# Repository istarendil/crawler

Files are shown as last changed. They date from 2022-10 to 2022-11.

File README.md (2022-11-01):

# Crawler robot
The **crawler robot** is a simple and low-cost physical platform for the initial study of [reinforcement learning](https://en.wikipedia.org/wiki/Reinforcement_learning) algorithms. It consists of a 2 DoF planar arm actuated by servomotors mounted on a mobile base with 2 free wheels .<br>

crawler
 <br>
The reinforcement learning algorithm used for the robot to find a sequence of actions that provide locomotion by its own is known as [**Q-learning**](https://es.wikipedia.org/wiki/Q-learning). The agent starts by executing random movements with his arm and when some sequence manages to mobilize the platform, the robot receives a positive reward. It is the repetition of this reward process that allows the robot to strengthen the movements that give it consistent locomotion and ignore the ones that do not.

policy

# Tools and materials
- Ardunio Uno board
- Matlab 2018
- 2 hobby servomotors
- Optical enconder 
- Bluetooth module
 
 # Demo
- The robotic agent [performing random movements](https://www.youtube.com/watch?v=am49DNG4l4M&list=PLQBwkbxMqU0CwwgrcaWHP4ouFjho0Iy4H&index=5) in order to learn an **optimal policy** through negative feedback.
- The robotic agent [executing a locomotion strategy](https://www.youtube.com/watch?v=am49DNG4l4M&list=PLQBwkbxMqU0CwwgrcaWHP4ouFjho0Iy4H&index=5) through a set of self-learned coherent movements

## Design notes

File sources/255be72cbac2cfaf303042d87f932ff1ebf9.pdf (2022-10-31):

## Teaching Reinforcement Learning using a Physical Robot

Michel Tokic | michel.tokic@hs-weingarten.de
Institute of Applied Research, University of Applied Sciences Ravensburg-Weingarten, Germany
Haitham Bou Ammar | haitham.bouammar71@googlemail.com
Department of Knowledge Engineering, Maastricht University, The Netherlands

Abstract

This paper presents a little crawling robot as a didactic instrument for teaching reinforcement learning. The robot learns a forward-walking policy from scratch in less than 20 seconds of reinforced sensorimotor interactions. The state space consists of two discretized dimensions, where the behavior is visualizable and comprehensible. In laboratory tutorials, students conduct experiments with a Toolbox written in Java, enabling to vary significant parameters such as the exploration rate or the discounting factor. Our experience as well students feedback in using the crawler reflects: (1) a more interesting lecture, (2) an increase in students’ motivation, and (3) an efficient and fast learning for students.

### 1. Introduction

Machine Learning is a fast growing field. Applications such as recommender and/or ranking systems are embedded in most search engines and social networking sites. Various other applications such as the Google driverless car and robotics, among others, are paving the way for new technologies and products in the near future.

Such applications raise a broad interest in learning about this new and exciting technology. For instance, over 100, 000 students attending Andrew Ng’s online lecture on Machine Learning clearly reflect this increasing interest. This interest elevation comes at the expense of providing the best tools to convey such a knowledge in an efficient and suitable manner. Machine learning is a massive field, which includes dif-

Appearing in Proceedings of the Workshop on Teaching Machine Learning at 29 th International Conference on Machine Learning, Edinburgh, Scotland, UK, 2012.

ferent areas of study. In an introductory course, typically few hours are assigned to reinforcement learning (RL), a technique for acquiring behavior based on reinforced sensorimotor interactions (Sutton and Barto, 1998). Aiming at conveying such a knowledge efficiently, we are looking for a vivid presentation of these various techniques. In particular we are looking for a simple to understand physical robot as a motivator for AI students (Kay, 2010). For starters and to better understand the delivered material, it is important to be able to visualize various aspects of the used algorithms, therefore, the learning problem should consist of a two dimensional state space. A robot fulfilling these requirements is the crawler (Kimura et al., 1997; Tokic et al., 2009) with its two degrees of freedom arm, shown in Figure 1. To couple the physical robot with a software kit, that allows the students to easily program a learning behavior, the open-source Teaching-Box has been introduced in former research (Ertel et al., 2009). This kit is implemented in Java and contains abstracted basic RL algorithms, allowing to design arbitrary experiments with this technology.

In this paper we reflect upon experience in using the crawler as an example of a physical demonstration in introductory AI courses (Ertel, 2011). It was clear that such a scheme has: (1) increased a students’ interest and motivation to learn about reinforcement learning, and (2) made the lecture more exciting as there is a hands-on and easy to experiment-with example.

### 2. The Crawler and Teaching-Box

The physical robot, shown in Figure 1, is a two degrees of freedom arm. The state space is described using the discrete joint angles gx and gy shown in Figure 2. The goal of the robot is to move forward. Therefore, the reward is the speed of the robot, i.e. the distance the center of gravity of the robot had moved in a given time step. Consequently, a positive reward is attained if the robot moves forward and a

Teaching Reinforcement Learning using a Physical Robot

negative one vice versa. The robot is controlled by an ATmega32 micro-controller board mounted at its top as shown in Figure 1(b). The joints of the robot are driven by servos and the robot’s movement–used to calculate the velocity–is measured using an optical encoder attached to one of the wheels. The board has outlets for the servos, a serial wireless transceiver, an outlet for the encoder, and a DIP switch to set various parameters.

(a) (b)
robot | time | state | reward | action
| | 0 | up | left | 0 | right
| | 1 | up | right | 0 | down
| | 2 | down | right | 0 | left
| | 3 | down | left | 1 | up
t | gy | gx | x | at

(c)

Figure 1. (a) The robot model with its two joints and the
(b) physical robot. Four steps of a simple forward-walking policy are shown in (c).

### 2.1. Reinforcement Learning

Reinforcement Learning (RL) is a technique for solving sequential decision making problems (Sutton and Barto, 1998). Typically, a learning problem is described as a Markov Decision Process (MDP) that basically consists of a state space, S, an action space, A, transition probabilities, P(s, a) : S × A × S → [0, 1] with s ∈ S and a ∈ A, a reward function R : S × A × S → R, and a discount factor γ ∈ [0, 1[. The goal in RL is to learn a policy π : S × A → [0, 1], with π(a|s) defining the probability of choosing action a in state s. The goal of an RL agent is to learn π so as to maximize the total discounted reward, defined by an utility function, V

π
(s) = Eπ

P∞
k=0 γ

k
rt+k+1|st = s

Algorithm 1 ValueIteration On The Crawler
1: Initialize V arbitrarily, e.g., V (s) = 0, for all s ∈ S

2: Initialize Ra
ss⁰ arbitrarily, e.g., r(s, a) = 0, for all r ∈ Ra
ss⁰
3: state ← (gx = 1, gy = 1)

4: loop
5: | ξ ← rand(0..1)
6: | if ξ < ε then
7: | a ← rand(A(state))
8: | else
9: | a ← argmaxaRa ss⁰ + γV (s
| 0
)
10: | end if
11: | successorState ← δ(state, a)
12: | observe r(state, a) and update Ra ss⁰
13: | for all s ∈ S do
14: | V (s) ← max a∈A(s)

h
| r(s, a) + γV δ(s, a)

i

15: | end for
16: | state ← successorState
17: end loop
gx | 1 | 2 | 3 | 4 | 5
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
↑↓ ↑↓ ↑↓ ↑↓ ↑↓
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
↑↓ ↑↓ ↑↓ ↑↓ ↑↓
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
↑↓ ↑↓ ↑↓ ↑↓ ↑↓
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
↑↓ ↑↓ ↑↓ ↑↓ ↑↓
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
↓ | ↓ | ↓ | ↓ | ↓
↓ | ↓ | ↓ | ↓ | ↓

J

↓ | ↓ | ↓ | ↓ | ↓
→

J→

J→

J→

J

J

↑ | | | | ↓
←

J←

J←

J←

J

Figure 2. The cartesian 5 × 5 grid-world model (left) and a cyclic walking policy (right). States within the cycle are labeled as J.

### 2.2. Reinforcement Learning on the Crawler

There are different suggested algorithms for solving the crawler problem. In assignments and lab tutorials for the introduction to AI course, we use a simplified Value Iteration algorithm without using transition probabilities. This scheme is described in Algorithm 1, which starts by initializing all state values to arbitrary numbers such as zeros. Starting from the upper left corner, stateinit = {gx = 1, gy = 1}, an action can be chosen according to an ε-greedy exploration policy. An action a performed in state transitions the arm to a neighboring successor state, state⁰ ← δ(state, a). The distance the robot moved forward/backward is utilized as the reward signal rt+1, which is measured as encoder tics after sending the action command to the servos. Subsequently the reward is memorized in the reward model Ra
s,s⁰ . Next, for all states the value iteration algorithm is performed using the so far sampled reward model Ra

s,s⁰ . Finally, the observed successor state, state⁰
, is
taken as the new actual state of the robot.

Students experimentation in this specific example is conducted by programming the previous algorithm within the Teaching-Box, explained in Section 2.3. The parameters γ and , as well as others, are allowed to vary so as to assess the behavior of the algorithm. This enables for a better understanding of RL and the overall problem.

### 2.3. Teaching-Box

In order to easily program RL algorithms for the crawler, we provide a simple Java software kit that allows: (1) test the efficacy of the algorithm in simulation, and (2) apply the algorithm on the real physical robot to see it running. The Teaching-Box (TB) is an easy to use Java RL library, which includes basic RL algorithms, e.g., Q-learning(λ) and SARSA(λ), as well function approximators such as CMACs or radial basis function networks. The TB is implemented in a way to easily allow students to directly vary parameters of the algorithms, generate plots, and other visualizations to better assess the quality of the learned behavior.

### 3. Class Room Experience

The crawler is used in AI classes for computer science master students in the second semester. For the laboratory tutorial lasting about 1.5 hours, basic knowledge of the Java programming language is required. At first, it is demonstrated how the crawler learns to walk forward in about 20 seconds. Further, the technicality and difficulty of the learning problem are explained as in Figure 1+2, by basically reflecting on the delayed feedback problem. This alone is able to raise interest for understanding the details of the problem. Then, the basic algorithms for solving MDPs are introduced, e.g., value iteration and Q-learning, which afterwards enables to start conducting experiments on the robot.

A typical task for a student is to observe and assess the robot’s learning behavior on different surfaces, for instance by comparing the progress of the robot through examining the learned V and reward functions, or measuring the traveled distance in a fixed time interval. Another experiment is the variation of the algorithmic parameters such as the discount factor or the exploration rate. For instance, if the exploration rate is set to one, then the robot will perform 100% random actions. In contrast, if the exploration rate is constantly set to zero, the robot will be completely exploit the current V -values, which rarely leads to the optimal policy in practice, and to sub-optimal cycles instead, see Figure 3. This allows to better understand the dilemma of exploration and exploitation inherent to reinforcement learning. In other experiments, using for example the Q-learning algorithm, students observe a much slower learning behavior. This is because standard Q-learning updates only one Q-value after performing an action, but which might be improved by utilizing eligibility traces (Singh and Sutton, 1996) in simulation. However, on the hardware robot using the ATmega32 microcontroller, we only have 2kB of memory, for which reason we found the modified value iteration algorithm to perform best.

Due to the small state space and the idea of being able to visualize basically everything in the algorithm, students are usually highly motivated in starting to program the physical robot. Furthermore, a lot of interesting questions and discussions are initiated, for instance, extensions to continuous states and/or actions spaces are of major interest. Other questions on how to best choose the algorithmic parameters were also detailed and further analyzed. Starting from this simple example, some students even decided to further pursue bachelor and master theses in our groups.

### 4. Conclusions

In this paper we have presented an idea of using the simple crawling robot in teaching introductory machine learning courses. The robot is described by a 5 × 5 grid world, for which reason it is easy to understand and visualize. The hands-on physical experiment using the TB has raised the interest and motivation by students to better understand and analyze the subject, which allows to asses the behaviors of certain parameters involved in the algorithmic design process. Our experience with such type of learning is positive and we like to recommend using such a system at different universities all over the world. The software kit is open-source and available for anybody to use¹ .
Demonstration videos and contact addresses for obtaining the robot are also available²
. In the current
SVN trunk, a beta release of a three dimensional visualization of the robot using PythonGL is also provided, which does not require to own the hardware robot. Besides this, the group of Jennifer S. Kay at

1
http://sourceforge.net/projects/teachingbox
2
http://www.tokic.com

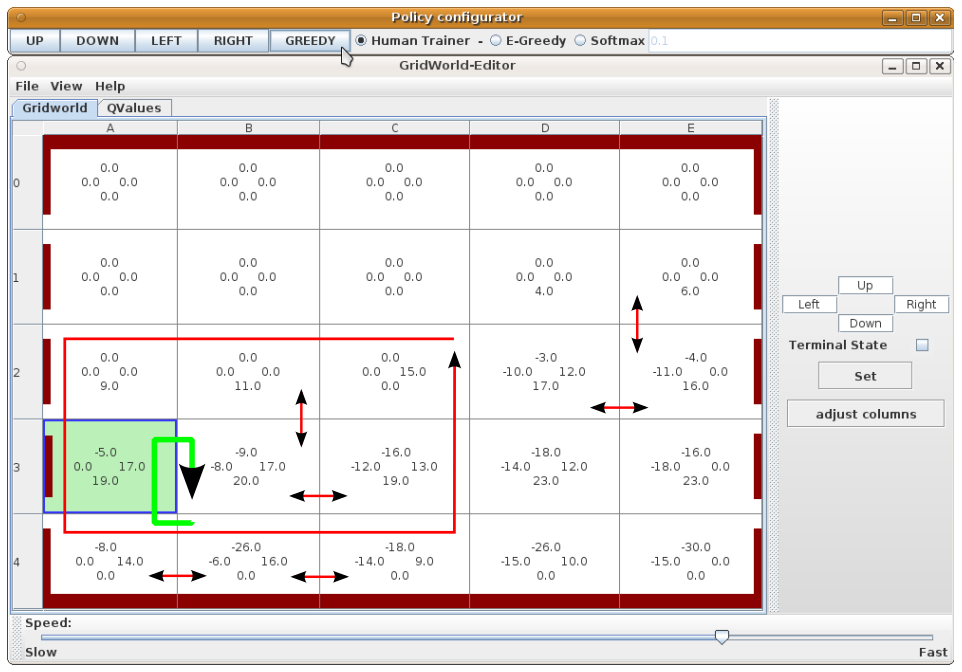
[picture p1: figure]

Figure 3. The grid-world editor of the Teaching-Box showing on top the ability to configure an action-selection policy. Numbers in cells indicate the reward r(s, a) observed from the environment. The cycle A3→B3→B4→A4 indicates the optimal cycle having an average reward of ¯r =

17+20−6−8
4 = 5.75 per action. All other marked cycles are sub-optimal, i.e. having a lower average reward/action ratio compared to the optimal cycle. The cell with surrounded border (A3) indicates the current state of the robot.

Rowan University currently develops a version of the
crawler utilizing LEGO Mindstorms (Montresor et al., 2011). Once finished, we plan to integrate it into the TB as well.

Acknowledgements

We like to thank Wolfgang Ertel and Jennifer S. Kay for sharing their experiences using the crawler.

References

W. Ertel. Introduction to Artificial Intelligence. Springer, 2011.
W. Ertel, M. Schneider, R. Cubek, and M. Tokic. The Teaching-Box: a universal robot learning framework. In International Conference on Advanced Robotics ICAR’09, pages 1–6, 2009.
J. S. Kay. Robots as recruitment tools in computer science: The new frontier or simply bait and switch? In AAAI Spring Symposium: Educational Robotics and Beyond, Technical Report SS-10-03. AAAI, 2010.
H. Kimura, K. Miyazaki, and S. Kobayashi. Reinforcement learning in POMDPs with function approximation. In Proceedings of the 14th International Conference on Machine Learning (ICML’97), pages 152–160, San Francisco, CA, USA, 1997. Morgan Kaufmann Publishers Inc.
S. Montresor, J. Kay, M. Tokic, and J. Summerton. Work in progress: Programming in a confined space - a case study in porting modern robot software to an antique platform. In Proceedings of the 41st ASEE/IEEE Frontiers in Education Conference, pages T3H–1–T3H–3, Rapid City, SD, USA, 2011. IEEE Press.
S. Singh and R. S. Sutton. Reinforcement learning with replacing eligibility traces. Machine Learning, 22:123–158, 1996.
R. S. Sutton and A. G. Barto. Reinforcement Learning: An Introduction. MIT Press, Cambridge, MA, 1998.
M. Tokic, J. Fessler, and W. Ertel. The crawler, a class room demonstrator for reinforcement learning. In Proceedings of the 22th International Florida Artificial Intelligence Research Society Conference, pages 160–165, Menlo Park, USA, 2009. AAAI Press.

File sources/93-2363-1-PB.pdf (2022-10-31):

## The Crawler, A Class Room Demonstrator for Reinforcement Learning

Michel Tokic and Wolfgang Ertel and Joachim Fessler
ZAFH Servicerobotik
University of Applied Sciences Ravensburg-Weingarten Doggenriedstrasse 38
88241 Weingarten, Germany

Abstract

We present a little crawling robot with a two DOF arm that learns to move forward within about 15 seconds in real time. Due to its small size and weight the robot is ideally suited for classroom demonstrations as well as for talks to the public. Students who want to practice their knowledge about reinforcement learning and value iteration can use a wireless connection to a PC and monitor the internal state of the robot such as the value function or the reward table. Due to its adaptivity, depending on the surface properties of the underground the robot may surprise its audience with unexpected but efficient walking policies. The GUI is open source and the robot hardware is available as a kit from the authors.

Introduction
In a classical introductory AI class, reinforcement learning has a narrow time slot of a few hours only. In our AI class we introduce value iteration (Bertsekas 1987) and Q-Learning (Watkins 1989) on discrete state- and action spaces and explain the exploration problem. Finally we give a short outlook on continuous problems and other algorithms.
In order to give a vivid presentation, we were looking for an example of a simple robot that enables us to directly demonstrate the learning algorithms. The state space of such a robot has to be two dimensional and the actions of the robot should be moves to neighbor states in the two dimensional grid world. A robot that very nicely fulfills these requirements was presented as a simulation in (Kimura, Miyazaki, and Kobayashi 1997). Figure 1 shows an outline of the little crawling robot with a two degree of freedom arm. In case of discrete positions and small movement angles of the two joints the state space can be approximated by a cartesian grid world as shown in Figure 2.
To move forward, the robot has to repeatedly perform a cycle of moves. An example for such a cycle is shown in Figure 2 on the right or in the sequence shown in Table 1. The task for the learning algorithms is to find a policy (which might be such a cycle) that maximizes the long-term cumulative reward. The reward is the speed of the robot, i.e. the distance the body of the robot moves forward per time step. Consequently, a move forward gives positive reward whereas any backward move yields negative reward.

Copyright -c 2009, Association for the Advancement of Artificial Intelligence (www.aaai.org). All rights reserved.

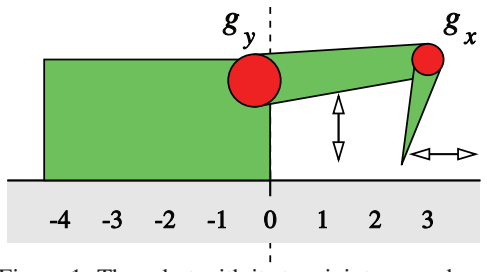
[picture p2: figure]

Figure 1: The robot with its two joints gx and gy.

gx 1 | 2 | 3 | 4 | 5

gy
1 -

←→-

←→-

←→-

←→-↑↓ ↑↓ ↑↓ ↑↓ ↑↓
2 -

←→-

←→-

←→-

←→-↑↓ ↑↓ ↑↓ ↑↓ ↑↓
3 -

←→-

←→-

←→-

←→-↑↓ ↑↓ ↑↓ ↑↓ ↑↓
4 -

←→-

←→-

←→-

←→-↑↓ ↑↓ ↑↓ ↑↓ ↑↓
5 -

←→-

←→-

←→-

←→-

↓↓↓↓↓

↓↓↓↓↓

↓↓↓↓↓
→-

→-

→-

→-

↑ | ↓
←-

←-

←-

| ←-

Figure 2: The cartesian 5 × 5 grid-world model (left) and a cyclic walking policy (right). States within the cycle are labled as -.

As a last but important requirement, the robot has to be small, lightweight and autonomous, such that it can easily be taken to the class room in a brief case and be demonstrated without an external power supply.
In the following sections we describe the robot hardware, the robot software and a graphical user interface (GUI) on the PC with a wireless connection to the real robot (Tokic 2006). For didactic purposes the GUI is very helpful because it allows us to view the value table and reward table and to watch the learning process of the robot.

The Robot
Hardware Setup
Our crawling-robot prototype as depicted in Figure 3 is controlled by an ATmega32 microcontroller board which

# 160 Proceedings of the Twenty-Second International FLAIRS Conference (2009)

robot | time | state | | reward | action
| | 0 | up | left | 0 | right
| | 1 | up | right | 0 | down
| | 2 | down | right | 0 | left
| | 3 | down | left | 1 | up
t | gy | gx | x | at

Table 1: Four steps of a simple cyclic forward walking policy.

is mounted on top of the robot. The joints of the robot are driven by servos and the robot’s movement is measured by an optical incremental encoder attached to one of the wheels. The board has outlets for the servos, a serial wireless transceiver, an outlet for the encoder and a DIP switch to setup several parameters. For instance one of these parameters inverts the encoder signal such that the robot learns a backward-moving strategy instead of moving forward.

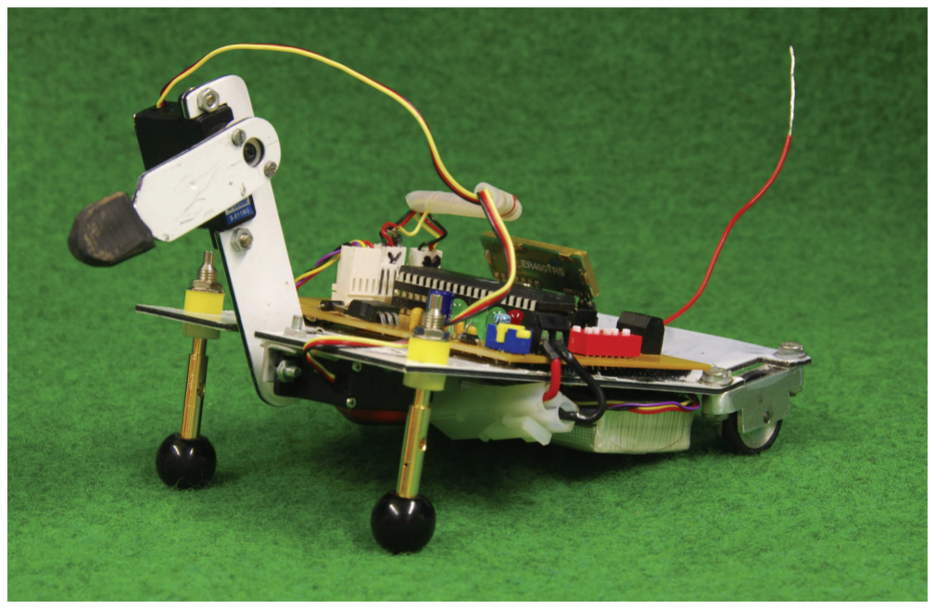
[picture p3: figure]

Figure 3: The crawling-robot prototype.

In addition to this prototype we developed a new version of the crawling robot as shown in Figure 4. Due to its robustness this robot is more suitable for lectures and laboratory tutorials. It has two wheels at the rear with a rigid axle. The axle is connected via a non-slip belt transmission to the encoder. This assembly reduces the sensor noise to a minimum. The board has the same features as the board above but with a bus interface for Dynamixel AX-12 servos in addition. These servos communicate with a half-duplex asynchronous packet-protocol on TTL-level with up to 1,000,000 bps. The maximum holding torque is about 1.17 Nm.

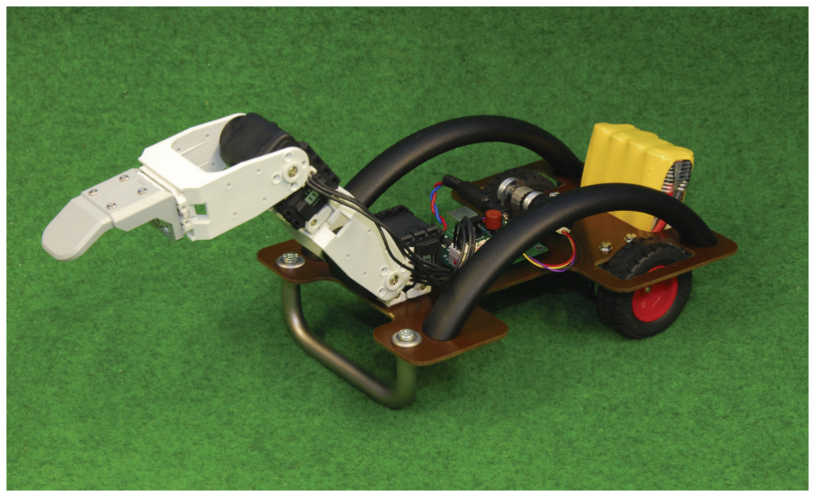
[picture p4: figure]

Figure 4: The new crawling robot for use in our laboratory tutorials.

The Learning Algorithm
We consider the reinforcement learning framework, see for example (Sutton and Barto 1998), where an agent, in our case the crawling robot, interacts with a Markovian decision process (MDP). At each time t ∈{0, 1, 2, ...} the agent is in a certain state st ∈S. After executing action at ∈A the agent receives a reward signal Ra
ss-

= E{rt+1|st =
s, at = a, st+1 = s-
} by passing into a successor state st+1 with probability Pa
ss-

= Pr{st+1 = s-|st = s, at = a},
∀s, s-
∈S,a ∈A. δ(s, a) denotes a transition function and represents the successor state safter action a has been
selected in s. The decision which action a is chosen in a certain state s is characterized by a policy, π(s)= a, which could also be stochastic π(s, a)= Pr{at = a|st = s}. A policy which maximizes the average reward over time is denoted as π∗. On the crawling robot we use the valueiteration algorithm (Bertsekas 1987; Sutton and Barto 1998; Powell 2007) for learning a cyclic deterministic policy π(s) by which the robot moves forward. The algorithm value iteration which we use on the robot basically works by assigning a numerical value V (s) ∈V to each state s ∈S where each state value represents the expected cumulated reward over time when following π(s). Based on these state values V in conjunction with Ra
ss-

a deterministic policy π(s) can be derived.
We adapted the value-iteration algorithm to perform on the crawling robot as depicted in Algorithm 1. Here a discounting factor 0 <γ ≤ 1 is used to specify the portion of influence of neighbor-state values V (δ(s, a)) on V (s). Since the robot is faced with a zero-knowledge environment after switching it on, a tradeoff between exploration (long-term optimization) and exploitation (short-term optimization) has to be done (Thrun 1992; Kaelbling, Littman, and Moore 1996; Sutton and Barto 1998). A very simple exploration technique is ε-Greedy exploration. Here the agent selects an action at random with a probability ε, uniformly and independently of V (s), instead of following π(s). Heuristically ε could be set to a high value at the beginning of the learning process and then be decreased over time. This ensures much exploration at the beginning and pure exploitation starting at some time t.

Algorithm 1 VALUEITERATION ON ROBOT
1: Initialize V arbitrarily, e.g., V (s)=0, for all s ∈S 2: Initialize Ra
ss-

arbitrarily, e.g., r(s, a)=0, for all r ∈
Ra
ss-3: state ← (gx =1,gy = 1)

4: loop
5: | ξ ← rand(0..1)
6: | if ξ<ε then
7: | a ← rand(A(state))
8: | else
9: | a ← argmaxaRa ss- + γV (s- )
10: | end if
11: | successorState ← δ(state, a)
12: | observe r(state, a) and update Ra ss-
13: | for all s ∈S do
14: | V (s) ← maxa∈A(s) r(s, a)+ γV (δ(s, a))
15: | π(s) ← argmaxa∈A(s)r(s, a)+ γV (δ(s, a))
16: | end for
17: | state ← successorState
18: end loop

As the value-iteration algorithm requires the rewards r(s, a) for each action a in state s, we simply save them into a memory table Ra
ss-

. After executing action a in s, we update the corresponding record r(s, a) in Ra
ss-

The Robot Software
The robot’s software architecture runs autonomously in a single thread on the ATmega32 microcontroller. This microcontroller comes with four “pulse-width modulated” (PWM) pins. We use two PWM-pins associated with Timer1A/B to directly position the joint-servos. The optical incremental encoder which is connected to an external-interrupt pin provides the reward signal r(s, a). An interrupt-service routine (ISR) counts the distance the robot moved within a small delay time t. It is activated subsequently after setting up the Timer1A/B registers by which we position the servos with respect to state s and action a.
In an endless loop the robot executes actions either with respect to the learned policy π(s) or exploration steps. After each action a value-iteration step for all s ∈S is performed. Subsequently the serial interface is polled to check if the GUI sent a command to which the microcontroller should respond. For instance such a command can be a request for transmitting V and Ra
ss-

to the GUI in order to display the robot’s “brain”.

Walking Robot Simulation
To demonstrate and test reinforcement learning algorithms on the two-dimensional grid-world, we developed a graphical user interface (GUI) which allows control of the real hardware robot and a simulated version of it. In addition to an animation of the robot’s x-z-projection the GUI comes up with a reward editor, a display of the current value table and a view of the current policy, Figures 5 and 6. A configuration editor enables the user to select the size of the state space and to specify the learning algorithm parameters, for example the discounting factor γ. In the configuration dialog it is also possible to configure a neural network for approximating the V -Function using back- or resilientpropagation (Rumelhart, Hinton, and Williams 1986; Riedmiller and Braun 1992).
In the view of the value table the user is able to control value iteration step-by-step using the “next iteration”-button. As well it is also possible to run the learning algorithm in a time-delayed or full-CPU-speed loop. Due to this feature the user can observe the robot’s learning progress over some time period. For this in each robot state s, which is a cell in the value table, we also display an arrow respresenting the robot’s current policy π(s) as shown in Figure 5.

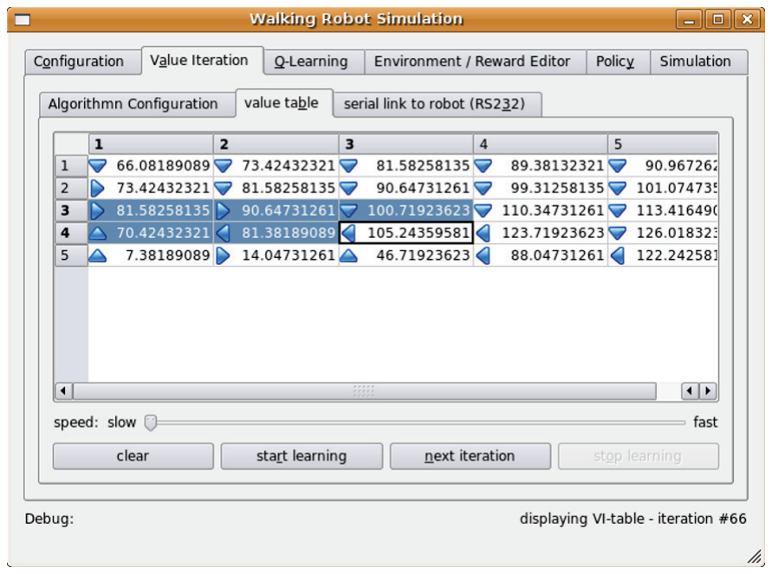
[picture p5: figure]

Figure 5: The simulator’s value table view with arrows for the current policy in each state. Please note the marked cyclic policy which the hardware robot learned after executing 66 value-iteration steps with respect to the environment as displayed in Figure 6.

Another important feature of the simulator is the reward editor as depicted in Figure 6. It allows the user to model the agent’s environment and thus to simulate the real hardware robot on different grounds. Alternatively the hardware robot’s reward table Ra
ss-

is displayed in this view when the simulator is connected to the robot. In combination with the robot’s value table this enables the user to get an insight into the robot’s “brain”. In the next section we will show how the simulator can be used by students to model different robot environments.
Apart from simulating the crawler, the simulator can also be used to simulate arbitrary two dimensional grid worlds with the four actions left, right, up and down.

Serial Robot Interface
One of the GUI’s main features is the serial robot interface by which the user is able to communicate wireless with the hardware robot. The interface enables the user to analyze the

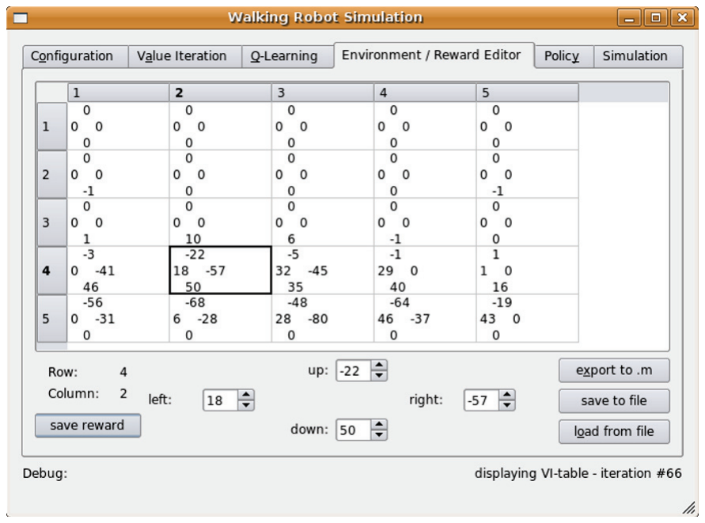
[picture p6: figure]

Figure 6: The simulator’s reward editor displaying the hardware robot’s reward table Ra
ss-

robot’s learning progress and to setup several learning process specific parameters. The link is realized by a RF04/400 USB telemetry module on the PC side, connected to the USB port. On the microcontroller side, we use an Easy-Radio ER400TRS transceiver which is directly connected to the microcontroller’s USART pins and which is also a part of the RF04/400 USB telemetry module. The two transceivers operate at the 433MHz frequency band with a serial baudrate of 19200. The GUI view provides to the user the following features:

- send control commands to the robot, e.g. “start walking” or “stop walking”
- retrieval of Ra
ss-

and V from the robot
- transfer Ra
ss-

and V from the GUI to the robot
- configuration of the robot’s discounting factor γ
- configuration of the robot’s exploration parameter ε
- retrieval of a counter, c, that indicates what distance the robot moved forward since the last counter reset
- reset of the distance counter c

Class Room Experience
We used the crawler in the AI class for the computer science master students. At the very beginning of the section on reinforcement learning we give a demonstration of the crawler learning to walk within about 20 seconds. This simple demo leads to a high motivation: the students want to know “how it works”. Then, after introducing value iteration, the students can perform their own experiments on the robot. Some of the possible experiments are described in the following.
In our laboratory tutorials a typical task for a student is to observe the robot’s learning behaviour on different surfaces. A part of this exercise is the examination of the robot’s learning progress by loading V and Ra
ss-

from the
robot into the GUI. This enables the student to identify the policy cycle and to verify it. This is done by computing

↓ ↓ ↓↓↓
→-

→-

↑ ↓↓↓
←-
| ←- ←- ←-
↑ ↑ ↑↑↑

↑↑ | ↑

→-

→-

→-

↓↓↓↓

→-

↑↓↓↓↓

→-←-

←-↑↑

↓↓ ↑↑

→-

→-

→-

Figure 7: Left: The robot’s policy learned on the laboratory carpet as depicted in Figure 3. Right: The robot’s policy learned on a table with a slippery surface as depicted in Figure 8. States within the cycles are labeled as -.

the average reward which is the ratio of the cumulated reward and the number of actions within the cycle. In the example of Figures 5 and 6 the robot’s average reward is
0+0+6+32+18−3
6 | =8.833. Afterwards the students simulate
the behaviour with a different discounting factor γ to get a sense about the effect of γ on learning times. For example a low γ leads to short learning times because value iteration converges faster. But unfortunately this leads to the problem that the optimal cycle is eventually not learned and sub-optimal cycles are learned instead of the optimal one. Since V (s) respresents the expected reward in the future, this effect is caused by too little information about states farther away from s. However solving this problem with a high
γ -
1 leads to longer learning times because value iteration converges slower. For the hardware robot we recommend γ =0.9 as the discounting factor since in all our experiments we got short learning times with it and we were able to find the optimal cycle.
Another parameter which can also be explored by the students is the exploration-rate parameter 0 ≤ ε ≤ 1. The choice of ε also impacts the learning time. For example, ε =1 leads to 100% exploration and the robot performs random actions all the time. On the other hand if ε =0, then the robot exploits greedily the current policy without exploring if there are other actions that yield more reward in the future. This effect is observable by the students as the robot will mostly stick in sub-optimal walking policies if ε =0 is configured. During the experiments the students find out that ε =0.1 is a good choice for balancing exploration and exploitation on this little crawling robot.
Some results of our experiments are shown in Figure 7 where the robot learned different policies due to different surface properties. We stopped the robot after a while of learning and examined the policy. The videos showing this learning process can be found on our laboratory website (AI-Lab HRW 2008).
Another very valueable exercise for the students is the inverse of the above task. Here the student has to design patterns of immediate rewards that simulate different surfaces on which the crawler has to move. Then the student uses the simulator to train a policy with value iteration. Now he/she can check if the policy meets the requirements.

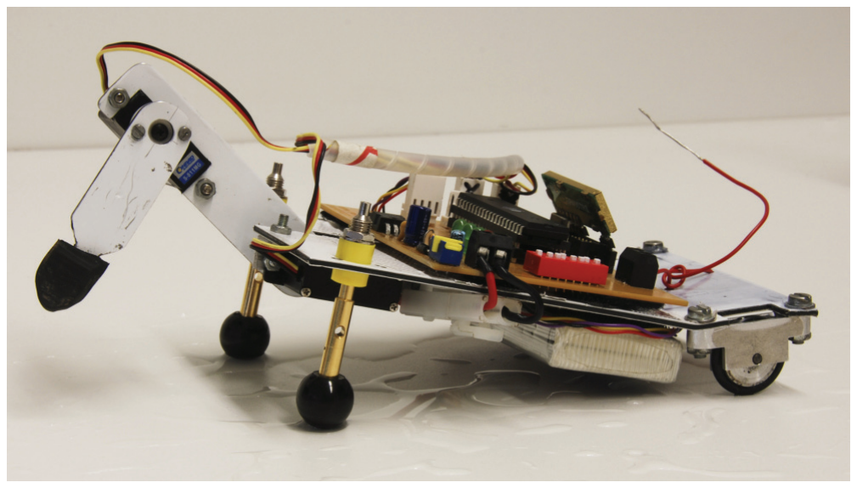
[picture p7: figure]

Figure 8: The crawling-robot prototype on a desk with a slippery surface.

As a first task, a flat surface is given. On such a ground, whenever the robot lifts its body a little bit, it can move effectively. An appropriate 5 × 5 reward pattern together with the resulting walking policy is given in Figure 9. With minimal vertical lifting, but maximal horizontal movement, the robot makes “big flat steps”.

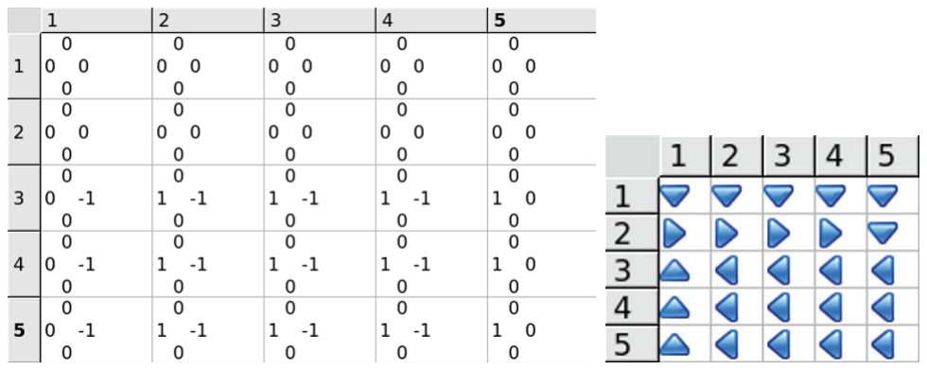
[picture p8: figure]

Figure 9: Simulated reward pattern for a flat surface (left) and the corresponding learned policy (right).

As a next task, the surface is rough, like it is if a human or animal walks in deep snow. Here the legs have to be lifted up high. Otherwise, the resistance or friction is very high. This can be modelled with high rewards if the body is lifted up high and low (but non-zero) rewards with small lifts. Figure 10 shows such a reward pattern together with the resulting walking policy.

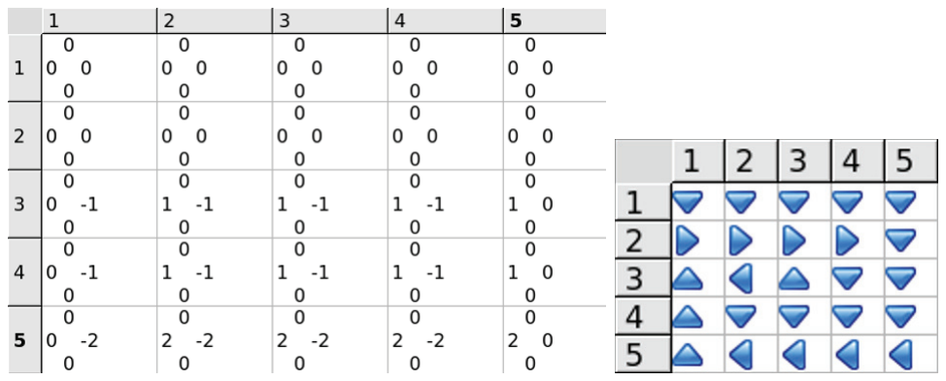
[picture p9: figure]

Figure 10: Simulated reward pattern for a rough surface (e.g. deep snow) and the corresponding learned policy.

Finally, the student can compare the simulated policies and reward patterns with the results from the experiments on the real robot. Differences are due to the fact, that for large angles of the robot joints, the geometry of the crawler movements is far from the Euclidean (rectangular) geometry in the simulation. This leads to the insight that even a robot as simple as our crawler can “invent” policies which a programmer never would have designed. For the students this is a very convincing motivation for the study of learning algorithms for robots.

Conclusions and Future Work

Due to the relatively small state- and action space the learning times on the real robot with its ATmega32 microcontroller are very short. Usually after about 10 to 30 seconds the value-iteration algorithm has learned a nice walking policy. Due to this impressive learning speed and its animal like shape and movements, in many lectures and talks the little crawling robot was able to attract the attention of students and spectators. Especially for an abstract and mathematically challenging subject such as reinforcement learning this is the best way of motivating students we can imagine. Even for us developers it was surprising to observe how sensible this very simple robot adapts its behaviour to the surface properties of the underground. The videos at (AI-Lab HRW 2008) show five policies learned on different surfaces. This can easily be demonstrated in the classroom e.g. by running the robot on a table or on a carpet and observing the difference.
Since this is an ongoing project we currently implement Q-Learning on the hardware robot as well as in the simulator as an alternative to value iteration. Once it is implemented the students are able to perform observations of the learning speed with respect to different learning algorithms. As a further extension we plan to implement different exploration/exploitation techniques, for example counter-based exploration as described in (Thrun 1992), since this will also impact the learning times.
Last but not least we want to encourage other universities to use this little robot for communicating the fascination in robot learning to their students. On our website (AI-Lab HRW 2008) we offer a hardware kit, an open-source simulator and the hardware robot’s open-source software.

Acknowledgements

We like to thank Hans-Peter Radtke, Markus Schneider, Arne Usadel and Tobias Bystricky for their contributions to the source code. We also thank Andy Stumpe and Christian Bieber for their support in taking measurements, video recordings and photos of the walking robot and for bringing the software to our website.
This work has been conducted within the ZAFH Servicerobotik (ZAFH 2008). The authors gratefully acknowledge the research grants of the state Baden-Wurttemberg and the ¨ European Union.

References

AI-Lab HRW. 2008. University of Applied Sciences
Ravensburg-Weingarten, Germany. | Website. | http:

//ailab.hs-weingarten.de [Online; accessed 20-February-2009].
Bertsekas, D. P. 1987. Dynamic Programming: Deterministic and Stochastic Models. Upper Saddle River, NJ, USA: Prentice-Hall, Inc.
Kaelbling, L. P.; Littman, M. L.; and Moore, A. P. 1996. Reinforcement Learning: A Survey. Journal of Artificial Intelligence Research 4:237–285.
Kimura, H.; Miyazaki, K.; and Kobayashi, S. 1997. Reinforcement Learning in POMDPs with Function Approximation. In ICML ’97: Proceedings of the Fourteenth International Conference on Machine Learning, 152–160. San Francisco, CA, USA: Morgan Kaufmann Publishers Inc. Powell, W. B. 2007. Approximate Dynamic Programming: Solving the Curses of Dimensionality. Wiley-Interscience. Riedmiller, M., and Braun, H. 1992. RPROP- A Fast Adaptive Learning Algorithm. Technical report, Proc. of ISCIS VII), Karlsruhe University, Germany.
Rumelhart, D. E.; Hinton, G. E.; and Williams, R. J. 1986. Learning Internal Representations by Error Propagation. Parallel Distributed Processing: Explorations in the Microstructure of Cognition, vol. 1: foundations 318–362. Sutton, R., and Barto, A. 1998. Reinforcement Learning: An Introduction. Cambridge, MA: MIT Press.
Thrun, S. B. 1992. Efficient Exploration In Reinforcement Learning. Technical report, Carnegie Mellon University, Pittsburgh, PA, USA.
Tokic, M. 2006. Entwicklung eines lernenden Laufroboters. Diploma thesis, University of Applied Sciences Ravensburg-Weingarten, Weingarten, Germany. Watkins, C. 1989. Learning from Delayed Rewards. Ph.D. Dissertation, University of Cambridge, England.
ZAFH. | 2008. | Zentrum fuer Angewandte Forschung
an Fachhochschulen. | Website. | http://www.
zafh-servicerobotik.de [Online; accessed 20-February-2009].

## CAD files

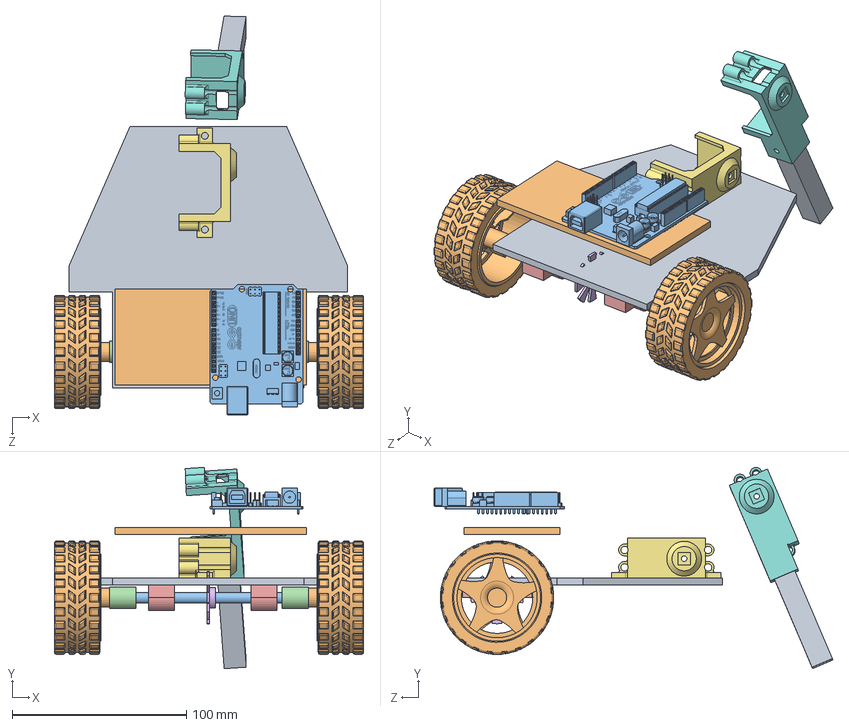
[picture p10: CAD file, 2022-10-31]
cad/Ensamblaje.SLDASM
177.4 x 115.6 x 228.9 mm
Chasis1
Rueda x 2
Eje
Cople x 2
Buje x 2
Encoder
Soporte2
Soporte
Brazo
Chasis2
Arduino UNO

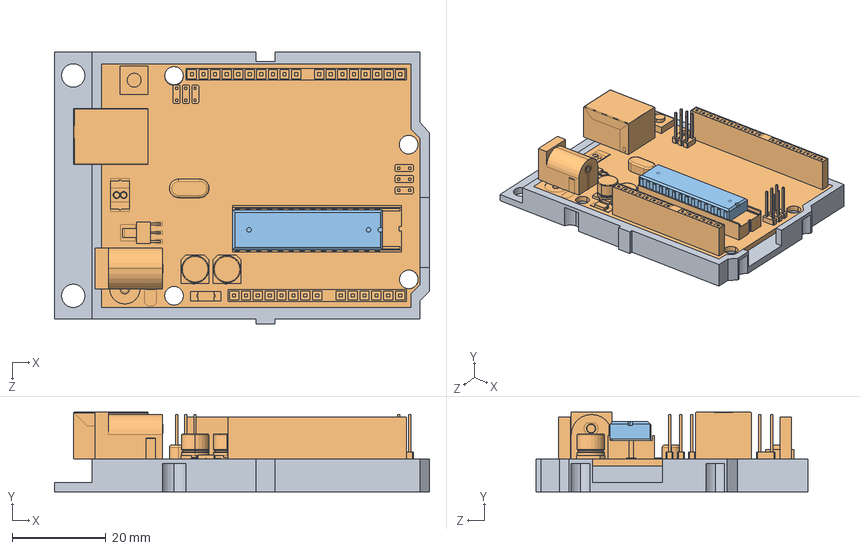
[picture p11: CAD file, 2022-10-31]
cad/Ardunio Uno .SLDASM
80.0 x 17.0 x 58.0 mm
Ardunio_holder.STEP
Ardunio-0.STEP
Top_chip.STEP

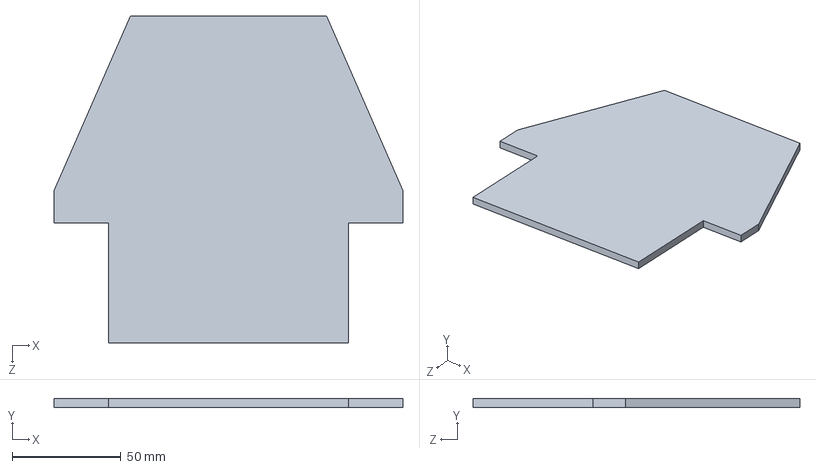
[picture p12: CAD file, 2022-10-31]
cad/Chasis1.SLDPRT
160.0 x 4.00 x 150.0 mm

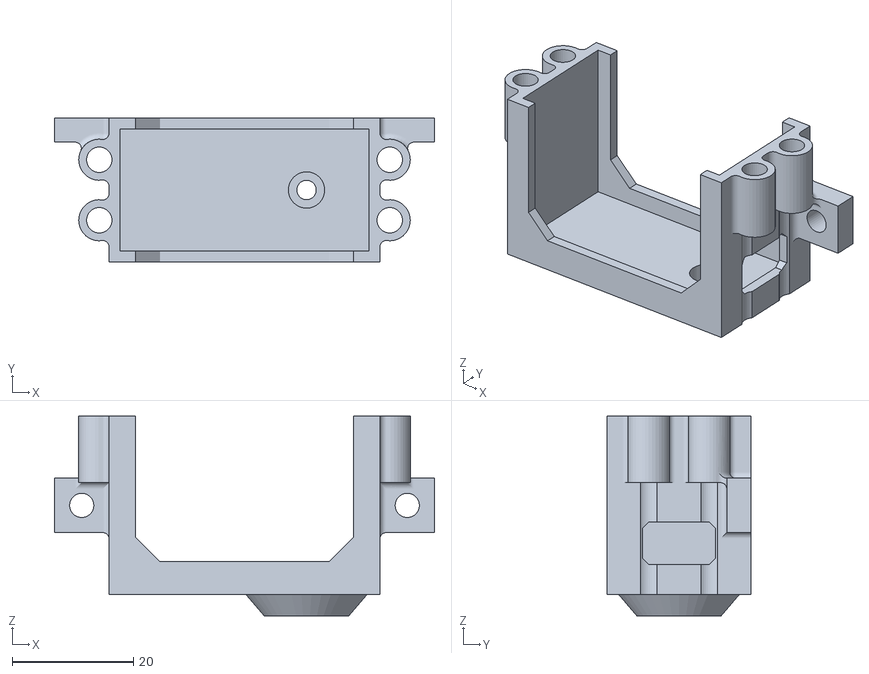
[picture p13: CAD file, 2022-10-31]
cad/print/Soporte2.STL
62.8 x 23.8 x 33.0

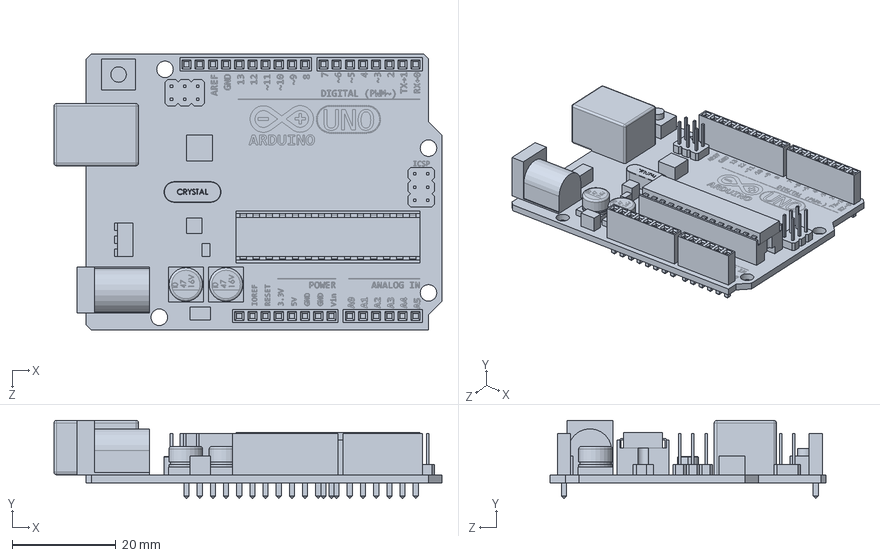
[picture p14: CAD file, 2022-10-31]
cad/Arduino UNO.SLDPRT
74.8 x 15.1 x 53.3 mm

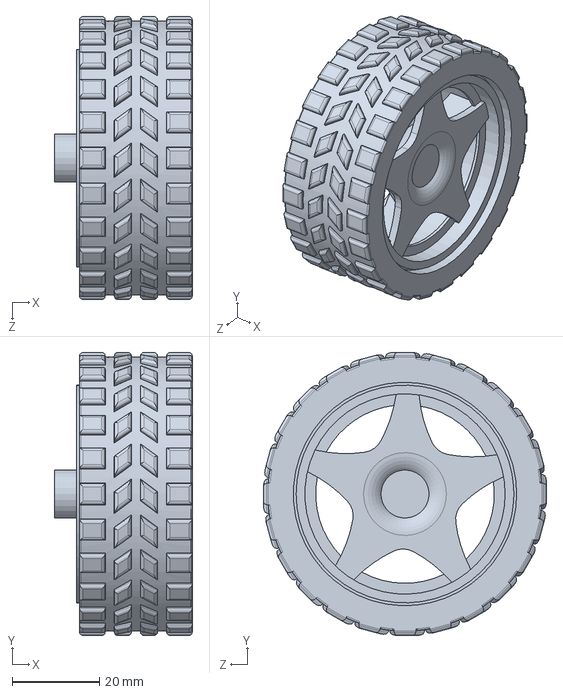
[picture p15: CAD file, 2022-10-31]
cad/Rueda.SLDPRT
31.7 x 65.0 x 65.0 mm

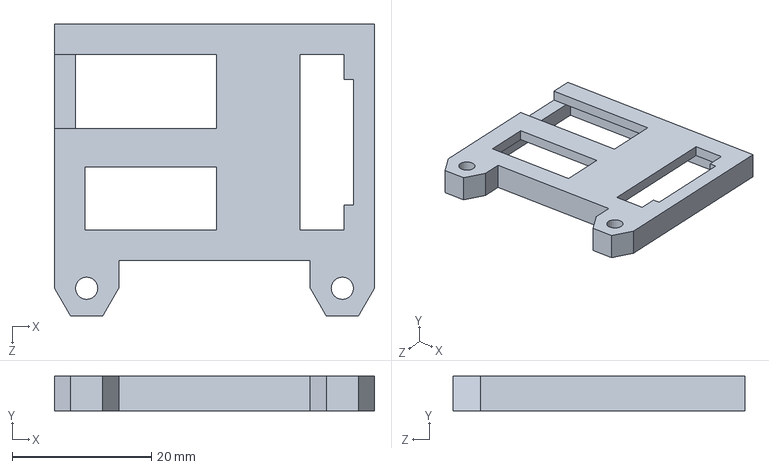
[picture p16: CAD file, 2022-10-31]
cad/Regukador.SLDPRT
46.0 x 5.00 x 42.0 mm

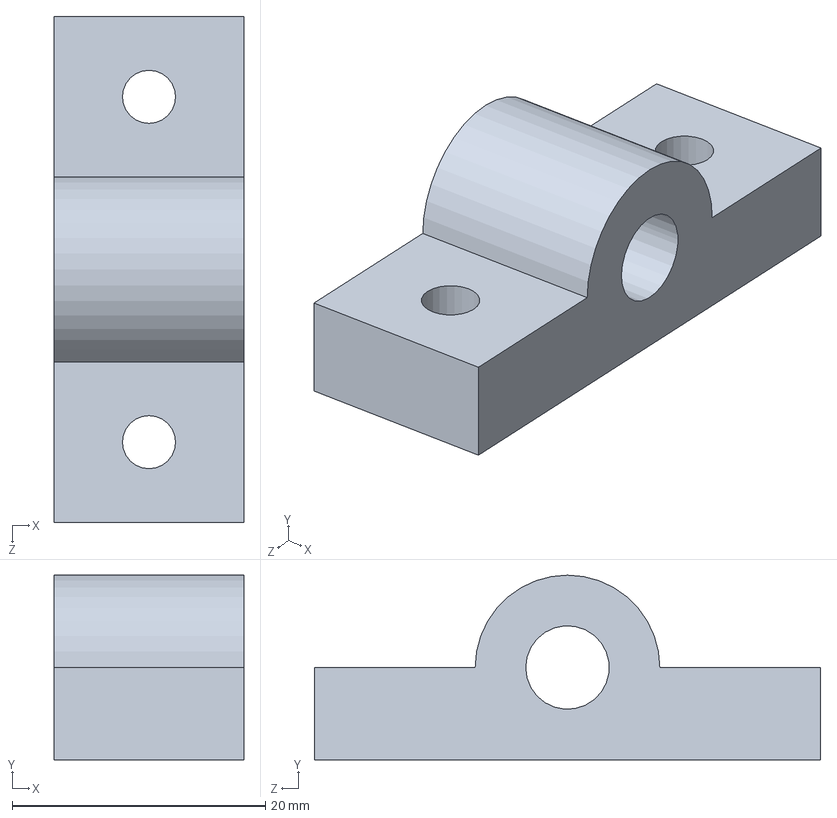
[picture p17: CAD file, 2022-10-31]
cad/Buje.SLDPRT
15.0 x 14.6 x 40.0 mm

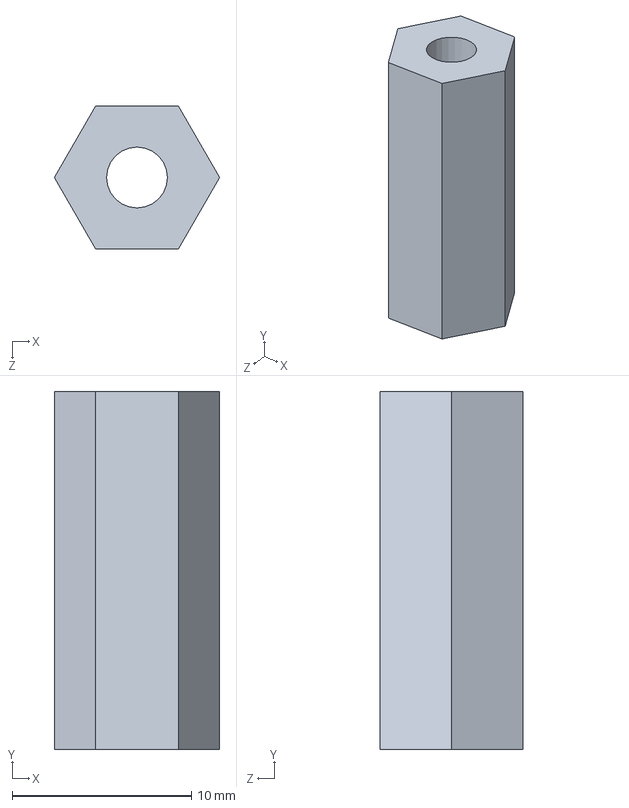
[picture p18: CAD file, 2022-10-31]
cad/Separador4.SLDPRT
9.24 x 20.0 x 8.00 mm

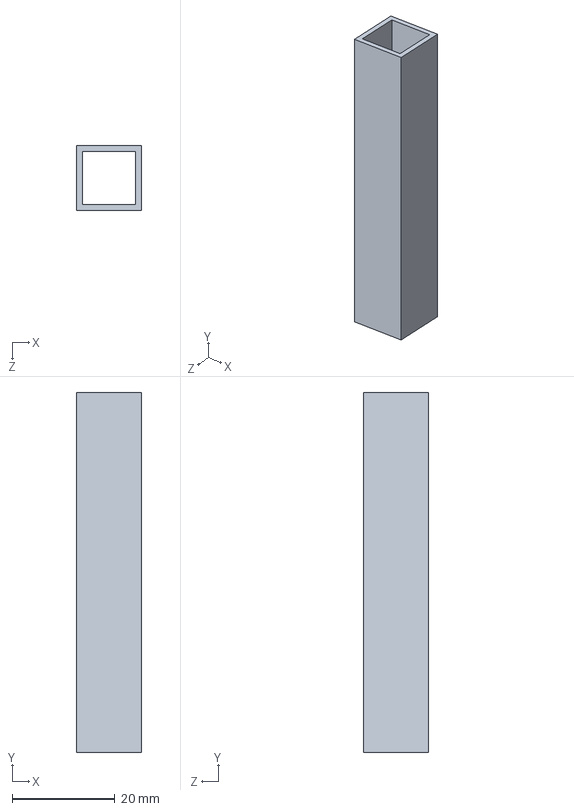
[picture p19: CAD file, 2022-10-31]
cad/Brazo.SLDPRT
12.7 x 70.0 x 12.7 mm

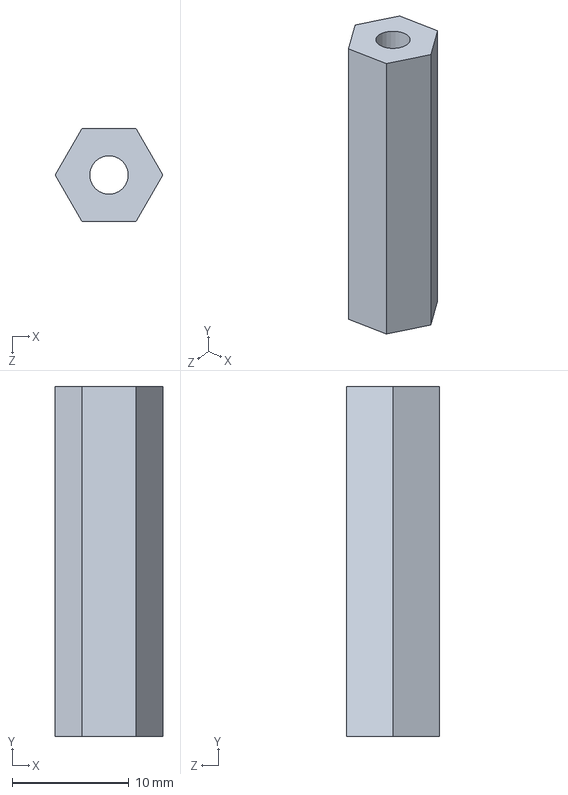
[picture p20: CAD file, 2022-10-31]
cad/Separador1.SLDPRT
9.24 x 30.0 x 8.00 mm

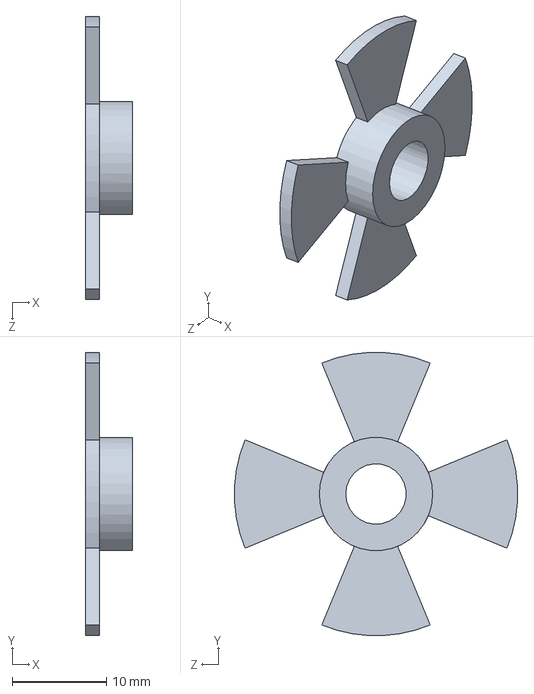
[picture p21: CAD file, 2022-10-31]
cad/Encoder.SLDPRT
5.00 x 30.0 x 30.0 mm

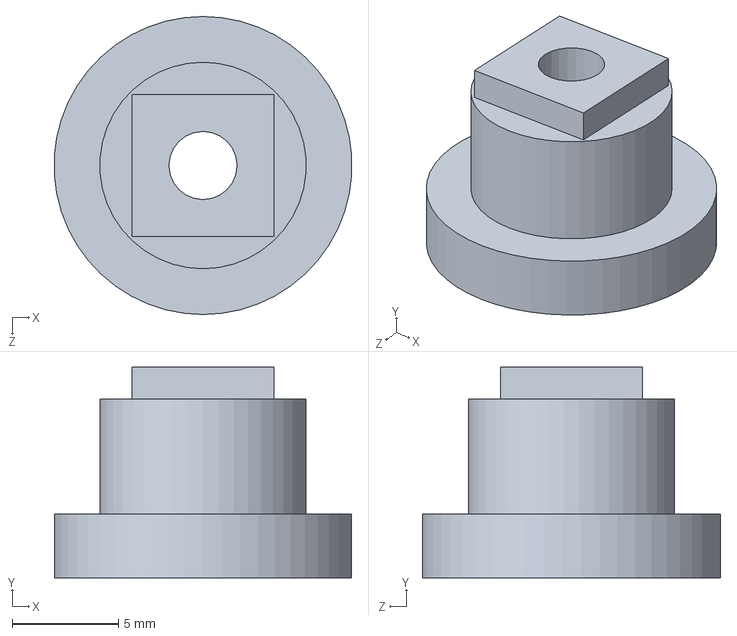
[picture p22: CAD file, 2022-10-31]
cad/pivote1.SLDPRT
14.0 x 9.90 x 14.0 mm

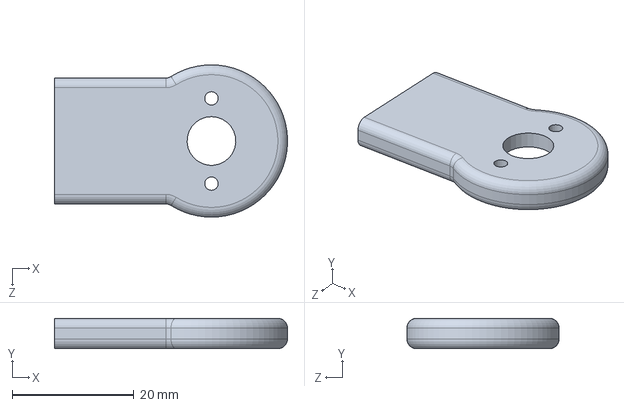
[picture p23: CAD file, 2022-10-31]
cad/Conector_2.SLDPRT
38.3 x 5.00 x 25.0 mm

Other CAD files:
cad/Eje.SLDPRT
cad/Ajuste-eje.SLDPRT
cad/Conector_1.SLDPRT
cad/Separador3.SLDPRT
cad/Chasis2.SLDPRT
cad/Cople.SLDPRT
cad/Pie.SLDPRT
cad/Separador2.SLDPRT
cad/Soporte.SLDPRT
cad/print/Ajuste-eje.STL
cad/print/Buje.STL
cad/print/Conector_1.STL
cad/print/Conector_2.STL
cad/print/Cople.STL
cad/print/Encoder.STL
cad/print/Pie.STL
cad/print/Regukador.STL
cad/print/Separador1.STL
cad/print/Separador2.STL
cad/print/Separador3.STL
cad/print/Separador4.STL
cad/print/Soporte.STL
cad/print/pivote1.STL

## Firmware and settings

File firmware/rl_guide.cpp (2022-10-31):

/*
This program functions as the "brain" of a reinforcement learning
agent whose goal is to crawl forward using two arms attached to two
servos.
For use in Arduino UNO
*/

#include <Servo.h>
#include <NewPing.h>
#define trigPin 10
#define echoPin 6
#define maxDistance 300
#define servo1Pin 13
#define servo2Pin 12
#define trigPin 10

NewPing ultrasonic(trigPin, echoPin, maxDistance);
Servo servo1;        //lower joint
Servo servo2;        //upper joint

/////////////////////////////////////////////////////////////////////////////////

//Computational parameters
float gamma = 0.75;      //look-ahead weight
float alpha = 0.1;       //"Forgetfulness" weight.  The closer this is to 1 the more weight is given to recent samples.

//Parameters for getAction()
float epsilon;           //epsilon is the probability of choosing an action randomly.  1-epsilon is the probability of choosing the optimal action

//Servo1 parameters
//This servo moves up with increased angle
const int numTheta1States = 6;
float theta1InitialAngle = 90.0;
float theta1Max = 100.0;                          //Can't exceed 110 or else arm will hit bar   //Need theta1Max and theta1Min between 0 and 180 
float theta1Min = 80.0;
float deltaTheta1 = (theta1Max - theta1Min)/(float(numTheta1States)-1.0);    //The change in servo1's angle when an action is performed on it
int s1 = int((theta1InitialAngle - theta1Min)/deltaTheta1);                  //This is an integer between zero and numTheta1States-1 used to index the state number of servo1
float delayTime1 = 4.5*deltaTheta1;                                 //The time in ms for the servo to move deltaTheta1

//Servo2 parameters
//This servo moves down with increased angle
const int numTheta2States = 6;
float theta2InitialAngle = 90.0;                
float theta2Max = 160.0;                        //Need theta2Max and theta2Min between 0 and 180 
float theta2Min = 90.0;
float deltaTheta2 = (theta2Max - theta2Min)/(float(numTheta2States)-1.0);    //The change in servo2's angle when an action is performed on it
int s2 = int((theta2InitialAngle - theta2Min)/deltaTheta2);                  //This is an integer between zero and numTheta2States-1 used to index the state number of servo2
float delayTime2 = 4.5*deltaTheta2;

//Initialize Q to zeros
const int numStates = numTheta1States*numTheta2States;
const int numActions = 4;
float Q[numStates][numActions];

//Initialize the state number. The state number is calculated using the theta1 state number and 
//the theta2 state number.  This is the row index of the state in the matrix Q. Starts indexing at 0.
int s = int(s1*numTheta2States + s2);
int sPrime = s;

//Initialize vars for getDeltaDistanceRolled()
float distanceNew = 0.0;
float distanceOld = 0.0;
float deltaDistance = 0.0;

//These get used in the main loop
float r = 0.0;
float lookAheadValue = 0.0;
float sample = 0.0;
int a = 0;

void setup(){
  servo1.attach(servo1Pin);
  servo2.attach(servo2Pin);
  servo1.write(theta1InitialAngle);
  servo2.write(theta2InitialAngle);
  delay(5000); 
}

//Returns an action 0, 1, 2, or 3
int getAction(){
  int action;
  float valMax = -10000000.0;
  float val;
  int aMax;
  float randVal;
  int allowedActions[4] = {-1, -1, -1, -1};  //-1 if action of the index takes you outside the state space.  +1 otherwise
  boolean randomActionFound = false;
  
  //find the optimal action.  Exclude actions that take you outside the allowed-state space.
  if((s1 + 1) != numTheta1States){
    allowedActions[0] = 1;
    val = Q[s][0];
    if(val > valMax){
      valMax = val;
      aMax = 0;
    }
  }
  if(s1 != 0){
    allowedActions[1] = 1;
    val = Q[s][1];
    if(val > valMax){
      valMax = val;
      aMax = 1;
    }
  }
  if((s2 + 1) != numTheta2States){
    allowedActions[2] = 1;
    val = Q[s][2];
    if(val > valMax){
      valMax = val;
      aMax = 2;
    }
  }
  if(s2 != 0){
    allowedActions[3] = 1;
    val = Q[s][3];
    if(val > valMax){
      valMax = val;
      aMax = 3;
    }
  }
  
  //implement epsilon greedy
  randVal = float(random(0,101));
  if(randVal < (1.0-epsilon)*100.0){    //choose the optimal action with probability 1-epsilon
    action = aMax;
  }else{
    while(!randomActionFound){
      action = int(random(0,4));        //otherwise pick an action between 0 and 3 randomly (inclusive), but don't use actions that take you outside the state-space
      if(allowedActions[action] == 1){
        randomActionFound = true;
      }
    }
  }    
  return(action);
}

//Given a and the global(s) find the next state.  Also keep track of the individual joint indexes s1 and s2.
void setSPrime(int action){  
  if (action == 0){
    //joint1++
    sPrime = s + numTheta2States;
    s1++;
  }else if (action == 1){
    //joint1--
    sPrime = s - numTheta2States;
    s1--;
  }else if (action == 2){
    //joint2++
    sPrime = s + 1;
    s2++;
  }else{
    //joint2--
    sPrime = s - 1;
    s2--;
  }
}


//Update the position of the servos (this is the physical state transition command)
void setPhysicalState(int action){
  float currentAngle;
  float finalAngle;
  if (action == 0){
    currentAngle = servo1.read();
    finalAngle = currentAngle + deltaTheta1;
    servo1.write(finalAngle);
    delay(delayTime1);
  }else if (action == 1){
    currentAngle = servo1.read();
    finalAngle = currentAngle - deltaTheta1;
    servo1.write(finalAngle);
    delay(delayTime1);
  }else if (action == 2){
    currentAngle = servo2.read();
    finalAngle = currentAngle + deltaTheta2;
    servo2.write(finalAngle);
    delay(delayTime2);
  }else{
    currentAngle = servo2.read();
    finalAngle = currentAngle - deltaTheta2;
    servo2.write(finalAngle);
    delay(delayTime2);
  }
}


//Get the reward using the distance the agent has moved since the last call
float getDeltaDistanceRolled(){
  //get current distance
  distanceNew = float(ultrasonic.ping());   
  deltaDistance = distanceNew - distanceOld;
  if (abs(deltaDistance) < 57.0 || abs(deltaDistance) > 230.0){         //don't count noise
    deltaDistance = 0.0;
  }
  distanceOld = distanceNew;
  return deltaDistance;
}


//Get max over a' of Q(s',a'), but be careful not to look at actions which take the agent outside of the allowed state space
float getLookAhead(){
  float valMax = -100000.0;
  float val;
  if((s1 + 1) != numTheta1States){
    val = Q[sPrime][0];
    if(val > valMax){
      valMax = val;
    }
  }
  if(s1 != 0){
    val = Q[sPrime][1];
    if(val > valMax){
      valMax = val;
    }
  }
  if((s2 + 1) != numTheta2States){
    val = Q[sPrime][2];
    if(val > valMax){
      valMax = val;
    }
  }
  if(s2 != 0){
    val = Q[sPrime][3];
    if(val > valMax){
      valMax = val;
    }
  }
  return valMax;
}

void printQ(){
  for(int i=0; i<numStates; i++){
    for(int j=0; j<numActions; j++){
      Serial.print(Q[i][j]);
      Serial.print(" ");
    }
    Serial.println(" ");
  }
  Serial.println(" ");
}

void initializeQ(){
  for(int i=0; i<numStates; i++){
    for(int j=0; j<numActions; j++){
      Q[i][j] = 10.0;               //Initialize to a positive number to represent optimism over all state-actions
    }
  }
}

/////////////////////////////////////////////////////////////////////////////////

const int rollDelay = 200;                   //allow time for the agent to roll after it sets its physical state
const float explorationMinutes = 1.0;        //the desired exploration time in minutes 
const float explorationConst = (explorationMinutes*60.0)/((float(rollDelay))/1000.0);  //this is the approximate exploration time in units of number of times through the loop

int t = 0;
void loop(){
  t++;
  epsilon = exp(-float(t)/explorationConst);
  a = getAction();           //a is beween 0 and 3
  setSPrime(a);              //this also updates s1 and s2.
  setPhysicalState(a);
  delay(rollDelay);                      //put a delay after the physical action occurs so the agent has time to move/roll before measuring the new position (before calling getDeltaDistanceRolled)
  r = getDeltaDistanceRolled();
  lookAheadValue = getLookAhead();
  sample = r + gamma*lookAheadValue;
  Q[s][a] = Q[s][a] + alpha*(sample - Q[s][a]);
  s = sPrime;
  
  if(t == 2){                //need to reset Q at the beginning since a spurious value arises at the first initialization (something from the rangefinder..)
    initializeQ();
  }
  
  //if(t == int(explorationConst)){
  //  printQ();
  //}
}
